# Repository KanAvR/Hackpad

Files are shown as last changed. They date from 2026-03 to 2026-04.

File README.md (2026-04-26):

# Hackpad
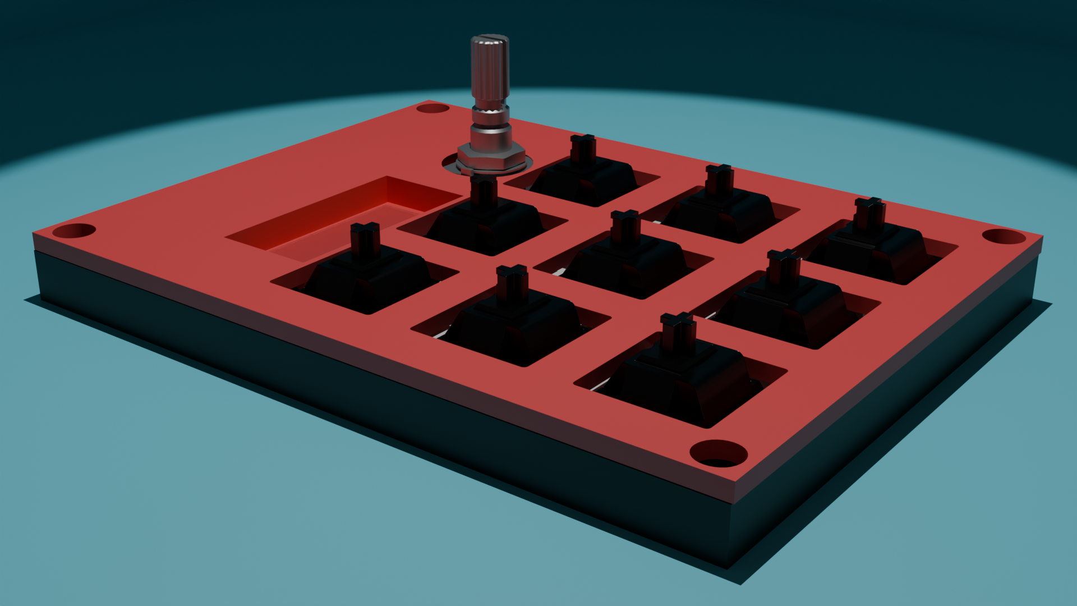
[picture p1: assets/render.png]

Hackpad is a 9 key macropad with a rotary encoder, an OLED Display and uses KMK firmware.

This will be used as a macropad for common desktop shortcuts such as, switching desktops; To boost productivity.

## Features:
- Open case because it looks cool
- 128x32 OLED Display
- EC11 Rotary encoder.
- 1 SK6812 MINI-E LED. 
- 9 Keys

## CAD Model:
Made in Blender.
The model is made of two seprate parts that will be screwed togeather to make the case.

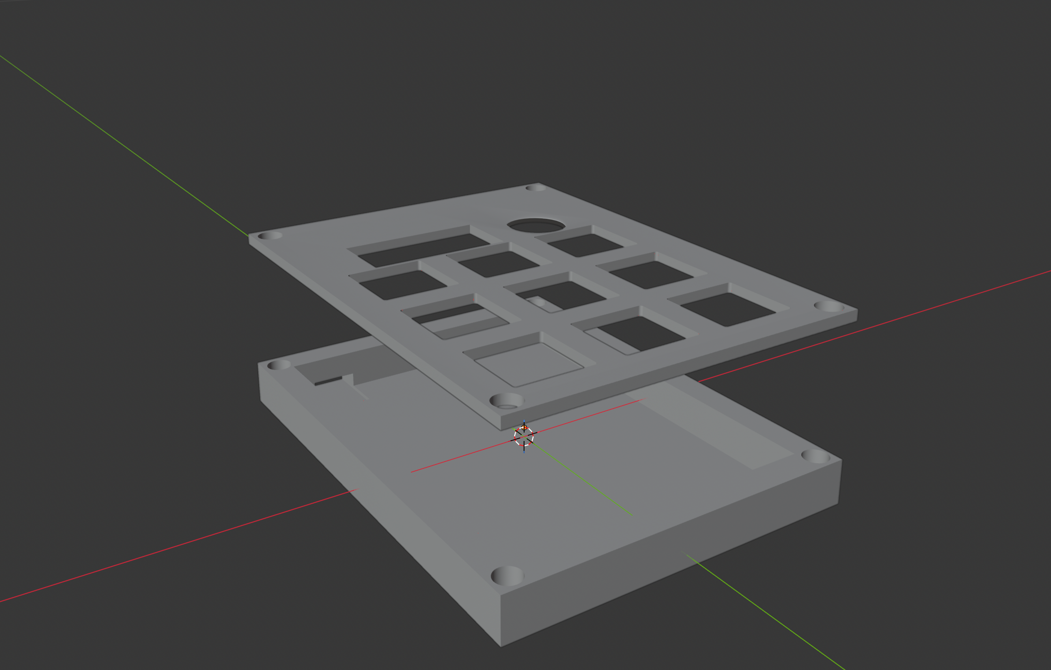
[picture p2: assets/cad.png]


## PCB
Made in KiCAD.
Schematic

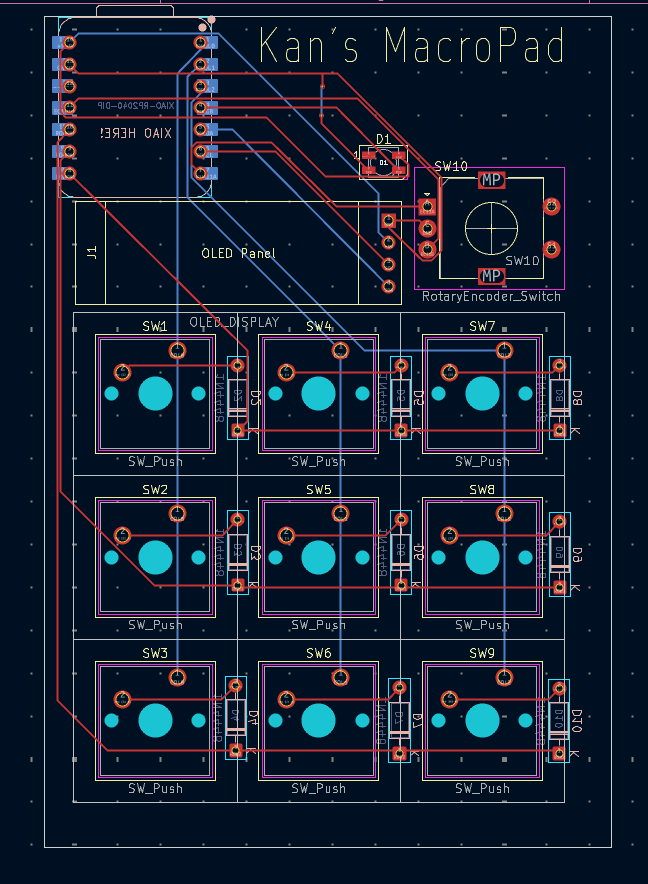
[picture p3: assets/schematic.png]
Schematic


PCB

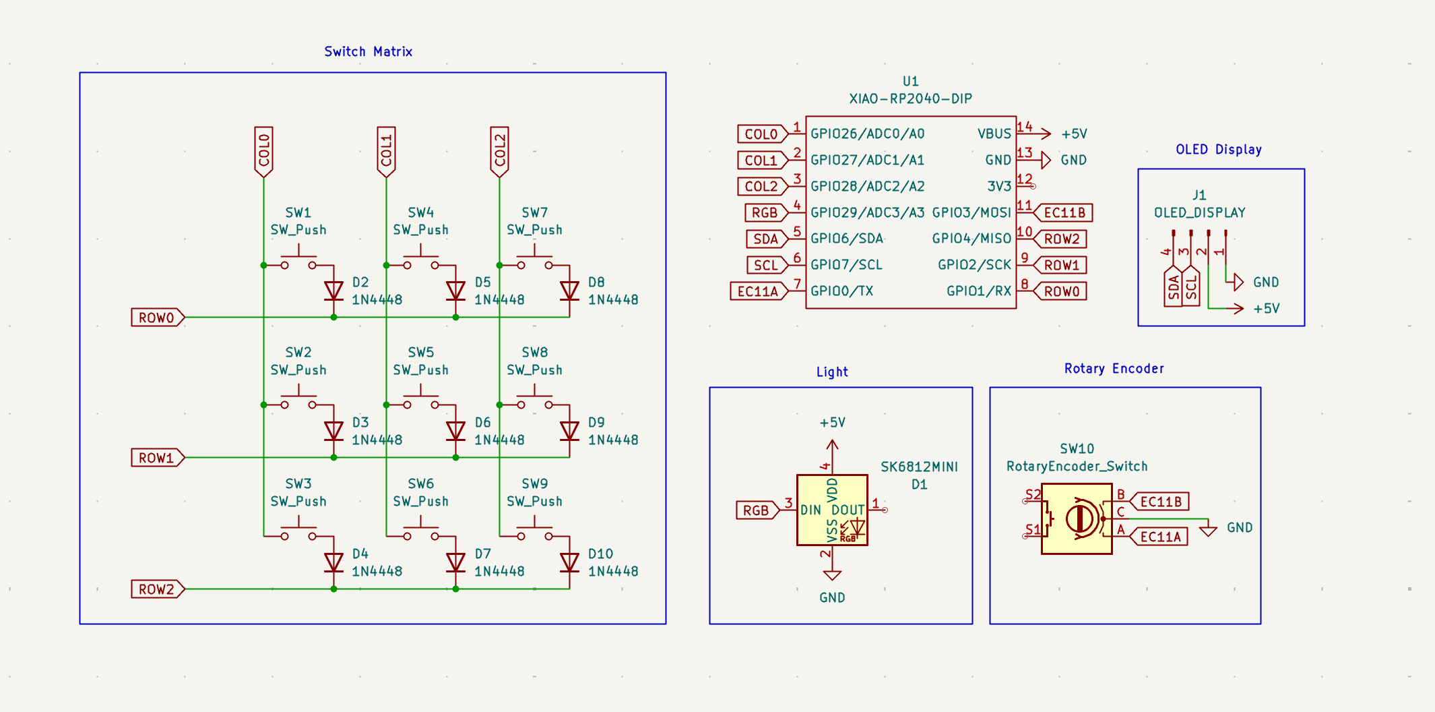
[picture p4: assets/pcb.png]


## Firmware Overview
This hackpad uses KMK firmware.
 
- The rotary encoder changes volume. Turning it clockwise increases the volume by 5% and turning it counter-clockwise decreases it by 5%. Pressing it toggles mute.
- The 9 keys will be bound to various hyprland shortcuts as and when required. Right now key 1-6 switch to workspaces 1-6, key 7 kills the focused window, key 8 toggles fullscreen, and key 9 takes a screenshot.
- The OLED will be used for showing volume status. It shows a bar that fills up as the volume increases and shows MUTE when muted.
- The SK6812MINI LED glows blue normally and turns red when muted.

## BOM:
| Name | Purpose | Qty | Price | Link | Distributor |
|---|---|-----|---|---|---|
| 0.91 inch blue OLED display module | Volume display (I already have this) | 1 | 0.00 | [Link](https://robocraze.com/products/0-91-inch-blue-oled-display-module) | Robo Craze |
| SK6812 MINI E RGB LED 3228 SMD Individually Addressable Full Color DC 5V (Pack of 100) | Mute status indicator (I already have this) | 1 | 0.00 | [Link](https://www.amazon.in/100PCS-Similar-WS2812B-Individually-Addressable/dp/B0DMNBBM9V) | Amazon |
| 1N4148 Fast Switching Diodes, 100V 300mA, Pack of 100, DO 35 Glass Zener Diodes for Electronic Projects | Preventing Ghosting (quantity is 1 because it comes in packs of 100, I will use 9) (I already have this) | 1 | 0.00 | [Link](https://www.amazon.in/100-Pieces-1N4148-Switching-High-Speed/dp/B079KJ91JZ) | Amazon |
| CentIoT EC11 10K Rotary Encoder Digital Potentiometer Coding Volume Control with switch 5 Pin 15mm Half handle (2PCS) | Volume knob (I already have this) | 1 | 0.00 | [Link](https://www.amazon.in/CentIoT-Encoder-Digital-Potentiometer-Control/dp/B0888RWNM1) | Amazon |
| Seeed Studio XIAO RP2040 Development Board | Connecting the hackpad to my computer (I already have this) | 1 | 0.00 | [Link](https://robocraze.com/products/seeed-studio-xiao-rp2040-development-board) | Robo Craze |
| Cherry MX Switches | Mechanical key switches (got from an old keyboard that stopped working) | 9 | 0.00 | N/A | N/A |
| DSA Keycaps | Keycaps for switches (got from an old keyboard that stopped working) | 9 | 0.00 | N/A | N/A |

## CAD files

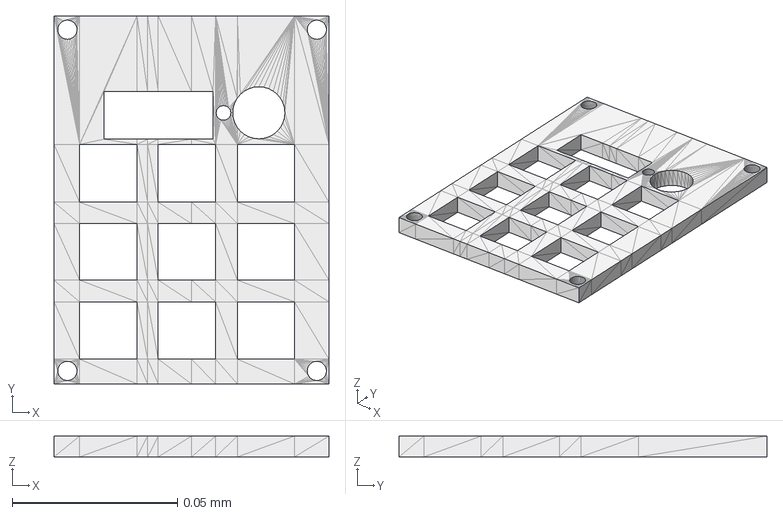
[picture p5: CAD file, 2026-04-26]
production/case_model_newtop.step
0.0832 x 0.111 x 0.00632 mm

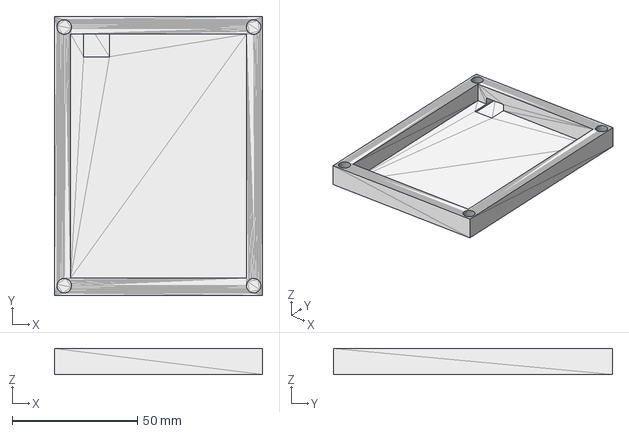
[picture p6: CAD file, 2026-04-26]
production/case_model_newbase.step
83.2 x 111.3 x 10.4 mm

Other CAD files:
production/case_model_newbase.stl
production/case_model_newtop.stl

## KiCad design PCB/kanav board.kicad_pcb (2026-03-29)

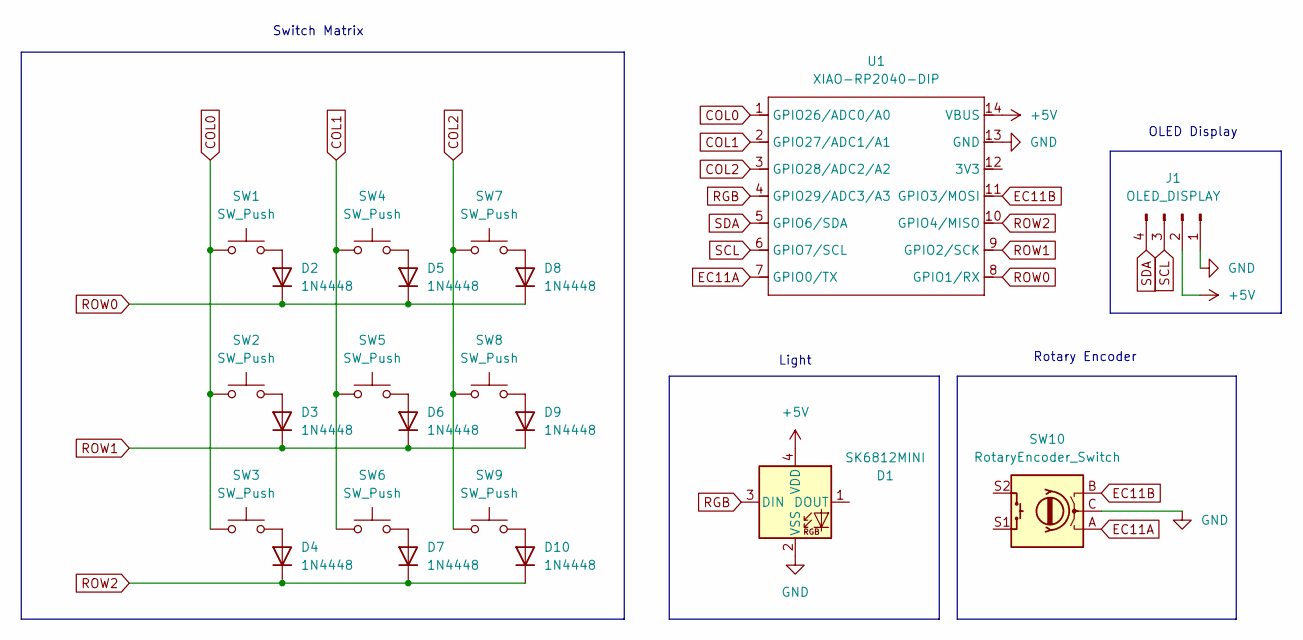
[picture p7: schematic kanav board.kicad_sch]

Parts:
D1: SK6812MINI; LED_SK6812MINI_PLCC4_3.5x3.5mm_P1.75mm
D2, D3, D4, D5, D6, D7, D8, D9, D10: 1N4448; D_DO-35_SOD27_P7.62mm_Horizontal
J1: OLED_DISPLAY; SSD1306-0.91-OLED-4pin-128x32
SW1, SW2, SW3, SW4, SW5, SW6, SW7, SW8, SW9: SW_Push; SW_Cherry_MX_1.00u_PCB
SW10: RotaryEncoder_Switch; RotaryEncoder_Alps_EC11E-Switch_Vertical_H20mm
U1: XIAO-RP2040-DIP

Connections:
+5V: D1.4 (VDD), J1.2, U1.14 (VBUS)
COL0: SW1.1, SW2.1, SW3.1, U1.1 (GPIO26/ADC0/A0)
COL1: SW4.1, SW5.1, SW6.1, U1.2 (GPIO27/ADC1/A1)
COL2: SW7.1, SW8.1, SW9.1, U1.3 (GPIO28/ADC2/A2)
EC11A: SW10.A, U1.7 (GPIO0/TX)
EC11B: SW10.B, U1.11 (GPIO3/MOSI)
GND: D1.2 (VSS), J1.1, SW10.C, U1.13 (GND)
unnamed: D2.2 (A), SW1.2
unnamed: D3.2 (A), SW2.2
unnamed: D4.2 (A), SW3.2
unnamed: D5.2 (A), SW4.2
unnamed: D6.2 (A), SW5.2
unnamed: D7.2 (A), SW6.2
unnamed: D8.2 (A), SW7.2
unnamed: D9.2 (A), SW8.2
unnamed: D10.2 (A), SW9.2
RGB: D1.3 (DIN), U1.4 (GPIO29/ADC3/A3)
ROW0: D2.1 (K), D5.1 (K), D8.1 (K), U1.8 (GPIO1/RX)
ROW1: D3.1 (K), D6.1 (K), D9.1 (K), U1.9 (GPIO2/SCK)
ROW2: D4.1 (K), D7.1 (K), D10.1 (K), U1.10 (GPIO4/MISO)
SCL: J1.3, U1.6 (GPIO7/SCL)
SDA: J1.4, U1.5 (GPIO6/SDA)

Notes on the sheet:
OLED Display
Light
Rotary Encoder
Switch Matrix

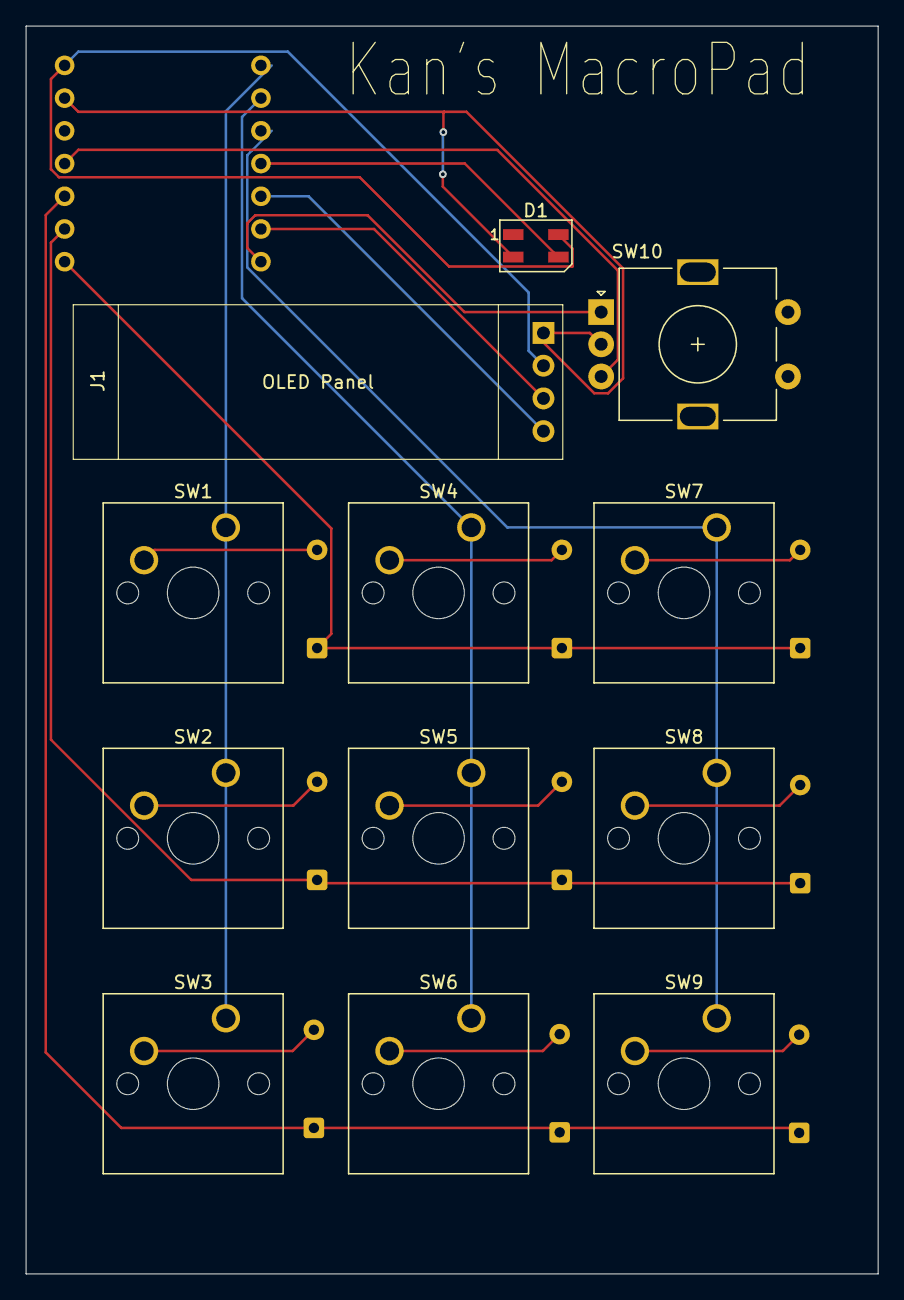
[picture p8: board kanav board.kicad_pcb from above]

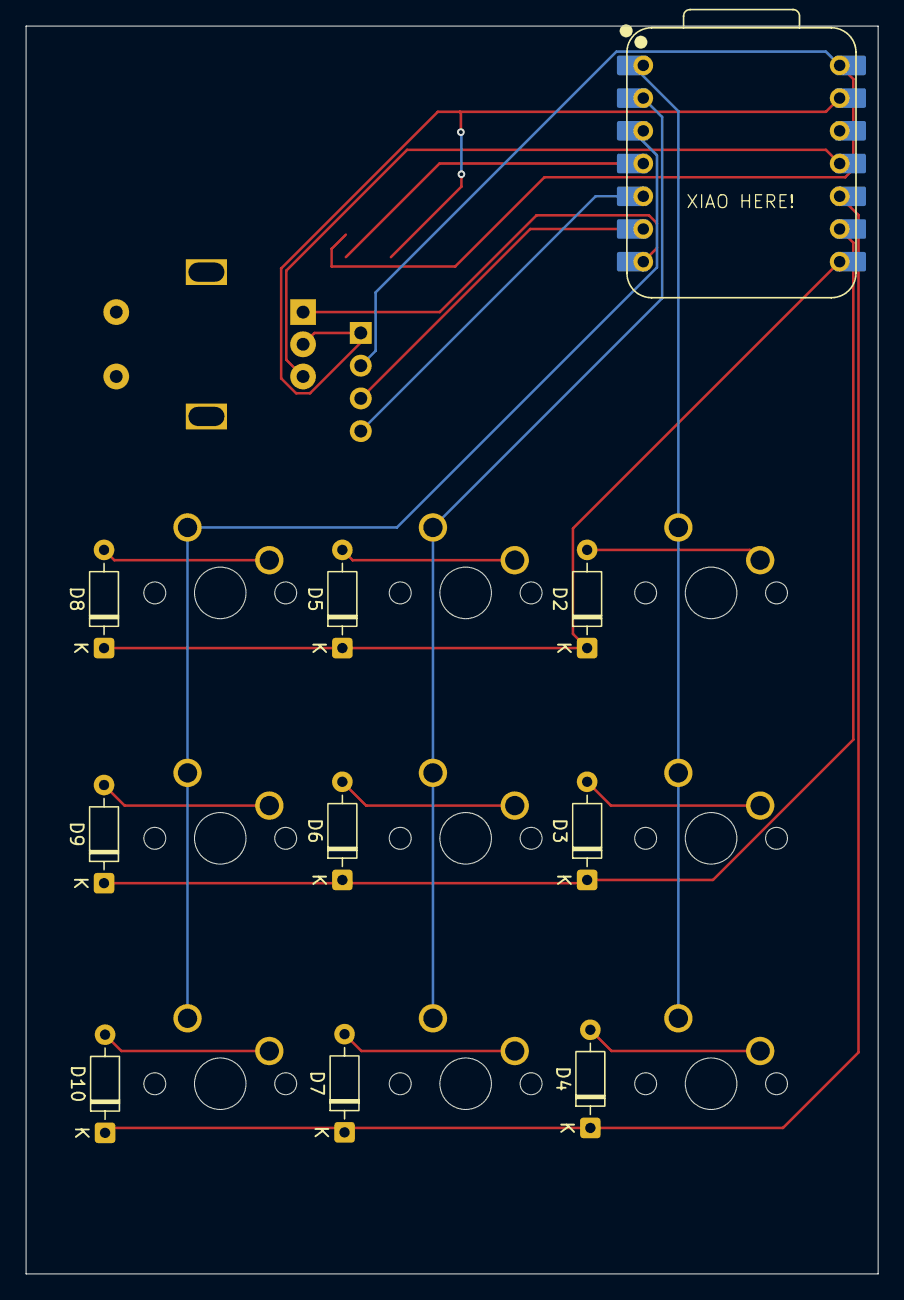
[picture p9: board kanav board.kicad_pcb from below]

Board: 2 copper layers, 66.1 x 96.9 mm, 22 parts (10 on the bottom side), 22 nets.

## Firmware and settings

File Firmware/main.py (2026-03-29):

import board
import busio
import displayio
import terminalio
import neopixel
import adafruit_displayio_ssd1306
from adafruit_display_text import label

from kmk.kmk_keyboard import KMKKeyboard
from kmk.keys import KC, make_key
from kmk.scanners.keypad import MatrixScanner
from kmk.scanners import DiodeOrientation
from kmk.modules.encoder import EncoderHandler
from kmk.extensions.media_keys import MediaKeys

COL_PINS = (board.D0, board.D1, board.D2)
ROW_PINS = (board.D7, board.D8, board.D9)
ENC_A    = board.D6
ENC_B    = board.D10
RGB_PIN  = board.A3
I2C_SDA  = board.SDA
I2C_SCL  = board.SCL

pixel = neopixel.NeoPixel(RGB_PIN, 1, brightness=0.2, pixel_order=neopixel.GRBW)
pixel[0] = (0, 0, 30, 0)

displayio.release_displays()
_i2c      = busio.I2C(I2C_SCL, I2C_SDA)
_disp_bus = displayio.I2CDisplay(_i2c, device_address=0x3C)
_display  = adafruit_displayio_ssd1306.SSD1306(_disp_bus, width=128, height=32)

_root = displayio.Group()
_display.root_group = _root

_lbl_title = label.Label(terminalio.FONT, text="VOL", color=0xFFFFFF, x=2,  y=5)
_root.append(_lbl_title)

_lbl_pct = label.Label(terminalio.FONT, text=" 50%", color=0xFFFFFF, x=98, y=5)
_root.append(_lbl_pct)

_lbl_mute = label.Label(terminalio.FONT, text="   ", color=0xFFFFFF, x=2, y=26)
_root.append(_lbl_mute)

_BX, _BY, _BW, _BH = 2, 13, 124, 11

_bg_bmp = displayio.Bitmap(_BW, _BH, 2)
_bg_pal = displayio.Palette(2)
_bg_pal[0] = 0x000000
_bg_pal[1] = 0xFFFFFF
for px in range(_BW):
    _bg_bmp[px, 0] = 1
    _bg_bmp[px, _BH - 1] = 1
for py in range(_BH):
    _bg_bmp[0, py] = 1
    _bg_bmp[_BW - 1, py] = 1
_root.append(displayio.TileGrid(_bg_bmp, pixel_shader=_bg_pal, x=_BX, y=_BY))

_FILL_INNER_W = _BW - 2
_FILL_INNER_H = _BH - 2
_fill_pal    = displayio.Palette(1)
_fill_pal[0] = 0xFFFFFF
_fill_bmp  = displayio.Bitmap(61, _FILL_INNER_H, 1)
_fill_tile = displayio.TileGrid(_fill_bmp, pixel_shader=_fill_pal, x=_BX + 1, y=_BY + 1)
_root.append(_fill_tile)


def _update_oled(vol, muted):
    global _fill_tile, _root
    if muted:
        _lbl_pct.text   = "MUTE"
        _lbl_mute.text  = "[M]"
        _fill_pal[0]    = 0x000000
        new_w = 1
        pixel[0] = (30, 0, 0, 0)
    else:
        _lbl_pct.text   = f"{vol:3d}%"
        _lbl_mute.text  = "   "
        _fill_pal[0]    = 0xFFFFFF
        new_w = max(1, vol * _FILL_INNER_W // 100)
        pixel[0] = (0, 0, 30, 0)
    _root.remove(_fill_tile)
    _fill_bmp  = displayio.Bitmap(new_w, _FILL_INNER_H, 1)
    _fill_tile = displayio.TileGrid(_fill_bmp, pixel_shader=_fill_pal, x=_BX + 1, y=_BY + 1)
    _root.append(_fill_tile)


_vol   = 50
_muted = False
_update_oled(_vol, _muted)


def _vol_up_press(key, keyboard, *args):
    global _vol, _muted
    _muted = False
    _vol   = min(100, _vol + 5)
    _update_oled(_vol, _muted)
    keyboard.keys_pressed.add(KC.VOLU)
    keyboard.hid_pending = True

def _vol_up_release(key, keyboard, *args):
    keyboard.keys_pressed.discard(KC.VOLU)
    keyboard.hid_pending = True

def _vol_dn_press(key, keyboard, *args):
    global _vol, _muted
    _muted = False
    _vol   = max(0, _vol - 5)
    _update_oled(_vol, _muted)
    keyboard.keys_pressed.add(KC.VOLD)
    keyboard.hid_pending = True

def _vol_dn_release(key, keyboard, *args):
    keyboard.keys_pressed.discard(KC.VOLD)
    keyboard.hid_pending = True

def _mute_press(key, keyboard, *args):
    global _muted
    _muted = not _muted
    _update_oled(_vol, _muted)
    keyboard.keys_pressed.add(KC.MUTE)
    keyboard.hid_pending = True

def _mute_release(key, keyboard, *args):
    keyboard.keys_pressed.discard(KC.MUTE)
    keyboard.hid_pending = True


VOL_UP = make_key(names=('VOL_UP',), on_press=_vol_up_press, on_release=_vol_up_release)
VOL_DN = make_key(names=('VOL_DN',), on_press=_vol_dn_press, on_release=_vol_dn_release)
MUTE   = make_key(names=('MUTE',),   on_press=_mute_press,   on_release=_mute_release)


keyboard = KMKKeyboard()

keyboard.matrix = MatrixScanner(
    column_pins       = COL_PINS,
    row_pins          = ROW_PINS,
    diode_orientation = DiodeOrientation.COL2ROW,
)

keyboard.extensions.append(MediaKeys())

enc      = EncoderHandler()
enc.pins = ((ENC_A, ENC_B, None, False),)
enc.map  = [
    ((VOL_DN, VOL_UP, MUTE),),
]
keyboard.modules.append(enc)

S  = KC.LGUI
SS = lambda k: KC.LGUI(KC.LSFT(k))

keyboard.keymap = [
    [
        S(KC.N1),   S(KC.N2),  S(KC.N3),
        S(KC.N4),   S(KC.N5),  S(KC.N6),
        S(KC.Q),    S(KC.F),   SS(KC.S),
    ],
]

if __name__ == '__main__':
    keyboard.go()

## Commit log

2026-03-29 Add README.md
    Added detailed information about the Hackpad project, including features, CAD model, PCB details, firmware overview, and bill of materials.
2026-03-29 formating
    Added PCB image section to the README.
2026-03-29 Change PCB image width to 500 pixels
    Updated PCB image size in README
2026-03-29 changed cad image
2026-04-22 Create CAD
2026-04-22 Change CAD model creation tool from Fusion to Blender
    Updated CAD model description and image source.
2026-04-22 Rename assets/CleanShot 2026-04-22 at 20.04.34@2x.png to cad.png
2026-04-24 Add files via upload
    fixed scaling issue with the 3d model
    [case model_newtop1.stl]
2026-04-24 fixed base scaling issue
    [case_model_newbase.stl]
2026-04-26 Add files via upload
    added step files and added the missing led hole
    [case_model_newbase.step, case_model_newtop.step]
2026-04-26 Update LED description for mute status indicator
2026-04-26 Update BOM prices to remove dollar signs
